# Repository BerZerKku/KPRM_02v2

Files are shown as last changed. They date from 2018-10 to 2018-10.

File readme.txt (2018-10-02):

Плата KPRM.
Сделана в OrCAD 16.6.

02v2

Код ПП: KPRM_02v2
Код ПП в сборе (1-16 команды): 2.141.180

Предназначена для использования в АВАНТ К400.

Изменения:
1. Обновлены элементы из базы (описания, сборка).
2. В преобразователе питания конденсатор С3 подключен на землю, а не в ОС. 
3. Элементы ОС преобразователя питания посажены на полигоны через термобарьеры.
4. Увеличин полигон для отвода тепла под DA1.
5. Отверстия крепления и разъема Х1 передвинуты согласно евромеханики. 
6. Поз. обозначения разъемов WAGO уменьшились на 1.
7. Добавлен разъем PLS-2 на землю.

Стэк:
18мкм  TOP
1.50мм e=4.5
18мкм  BOTTOM

Материал: FR4 
Финишное покрытие контактных площадок: HAL
Паяльная маска: зеленая.
Вырезы на плате нет.
Отверстия указаны ДО металлизации.
	Отв.	Метал.	Диам.	Кол.
	0.500	есть	0.4		220
	1.000	есть	1.0		194
	2.000	есть	1.8		64
	2.700	есть	2.7		2
	2.700	нет		2.7		2

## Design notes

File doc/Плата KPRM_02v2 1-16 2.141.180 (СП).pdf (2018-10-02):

Напечатано: 02 октября 2018 г. 12:02:07, Щеблыкин Михаил Владимирович
Поз. | Наименование | Корпус | Кол. | Поз. по Э3 | Примечание
| Документация
| Сборочный чертеж 2.141.180 | | 1
| Детали
1 | [KPRM_02v2] Печатная плата KPRM_02v2 2L/200um/0.4mm | | 1
| Прочее
| Реле
2 | [G3VM-351E] Реле G3VM-351E Omron | SOIC6 | 1 | AV1
3 | [G6S224DC] Реле G6S224DC 24VDC 2 Form C 0.5A/125VAC Omron | DIP8 | 16 | K1-K16
| Конденсаторы
7 | [1210-X7R-50V-10uF -10%] Чип-конденсатор 1210 X7R 50V 10uF 10% | 1210 | 2 | C1, C7 | Допустимые замены: [1210-X7R-50V-4.7uF-10%] Чип-конденсато р 1210 X7R 50V 4.7uF 10%
8 | [0805-X7R-50V-0.1u F-10%] [+]Чип-конденсатор 0805 X7R 50V 0.1uF 10% | 0805 | 4 | C2, C4, C5, C8
9 | [1206-X7R-50V-1uF-10%] [+] Чип-конденсатор 1206 X7R 50V 1uF 10% | 1206 | 1 | C3
10 | [0805-X7R-50V-0.01 uF-10%] Чип-конденсатор 0805 X7R 50V 0.01uF 10% | 0805 | 1 | C6

2.141.180

| Лист | № докум | Подп. | Дата
Разраб. | Щеблыкин М.В. | | 01.10.2018 | Плата KPRM_02v2 1-16 (Плата KPRM_02v2 1-16) | Лит. | Лист | Листов
Провер. | Вершинин А.С. | | 01.10.2018 | | | 1 | 4
Т.контр. | Бокова Т.И. | | 01.10.2018 | | Прософт-Системы
Н.контр. | Назаренко А.Н. | | 01.10.2018
Утв. | Чирков А.Г. | | 01.10.2018

| Предохранители,держатели предохранителей
18 | [P6SMB300CA] Диод P6SMB300CA | SMB(DO -214 | 32 | VD1, VD2, VD4-VD33
| Резисторы
20 | [1206-18K-5%] Чип-резистор 1206 18K 5% | 1206 | 16 | R1, R24-R38
21 | [1206-2K-5%] Чип-резистор 1206 2K 5% | 1206 | 18 | R2-R18, R22
22 | [1206-270-5%] Чип-резистор 1206 270 5% | 1206 | 1 | R19
23 | [1206-1K-5%] Чип-резистор 1206 1K 5% | 1206 | 1 | R20
24 | [1206-20K-5%] Чип-резистор 1206 20K 5% | 1206 | 1 | R21
25 | [1206-10K-5%] Чип-резистор 1206 10K 5% | 1206 | 1 | R23
26 | [1206x4-4.7K-5%] Чип-резисторная сборка 1206x4 4.7K 5% | SMD8 | 4 | RR1-RR4
| Микросхемы
32 | [LM317EMP] Микросхема LM317EMP SOT-223 TI | SOT223 | 1 | DA1 | Допустимые замены: [LM317AEMP] Микросхема LM317AEMP SOT223 TI
33 | [LM293D] Микросхема LM293D сдвоенный компаратор SO8 STM | SOIC8 | 1 | DA2
34 | [ULN2803ADW] Микросхема ULN2803ADW SOIC18 TI | SOIC18 | 4 | DD1-DD4

2.141.180

Лист

2 Изм | Лист | № докум | Подп. | Дата

| Диоды,светодиоды,супрессоры,стабилитроны
38 | [STPS160U] Диод STPS160U SMB STM | SMB(DO -214 | 1 | VD3
| Соединители
42 | [09031646921] Соединитель DIN EN 60303-2-C64MS-C1A-2 | DIN96 | 1 | X1
43 | [231-576/001-000] Вилка 1,2X1,2 шаг 5,08 мм (50 шт) | 16 | 2 | X2, X4
44 | [232-376] Угловая Вилка 5,08 мм 16-поз (25 шт) | 16 | 2 | X3, X5
45 | [PLS-40] Разъем PLS-40 | 2 | 2 | X6

2.141.180

Лист

3 Изм | Лист | № докум | Подп. | Дата

Лист регистрации ревизий

№ ревизии | № замененных (измененных) страниц | Дата ревизии | Краткое содержание и причина внесения изменений | Примечание
0 | вновь | 01.10.18

2.141.180

4

Лист Изм. | Лист | № докум. | Подп. | Дата

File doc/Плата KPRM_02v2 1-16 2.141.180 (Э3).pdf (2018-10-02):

K

8C | 11 7C | 12 6C | 13 5C | 14 4C | 15 3C | 16 2C | 17 1C | 18

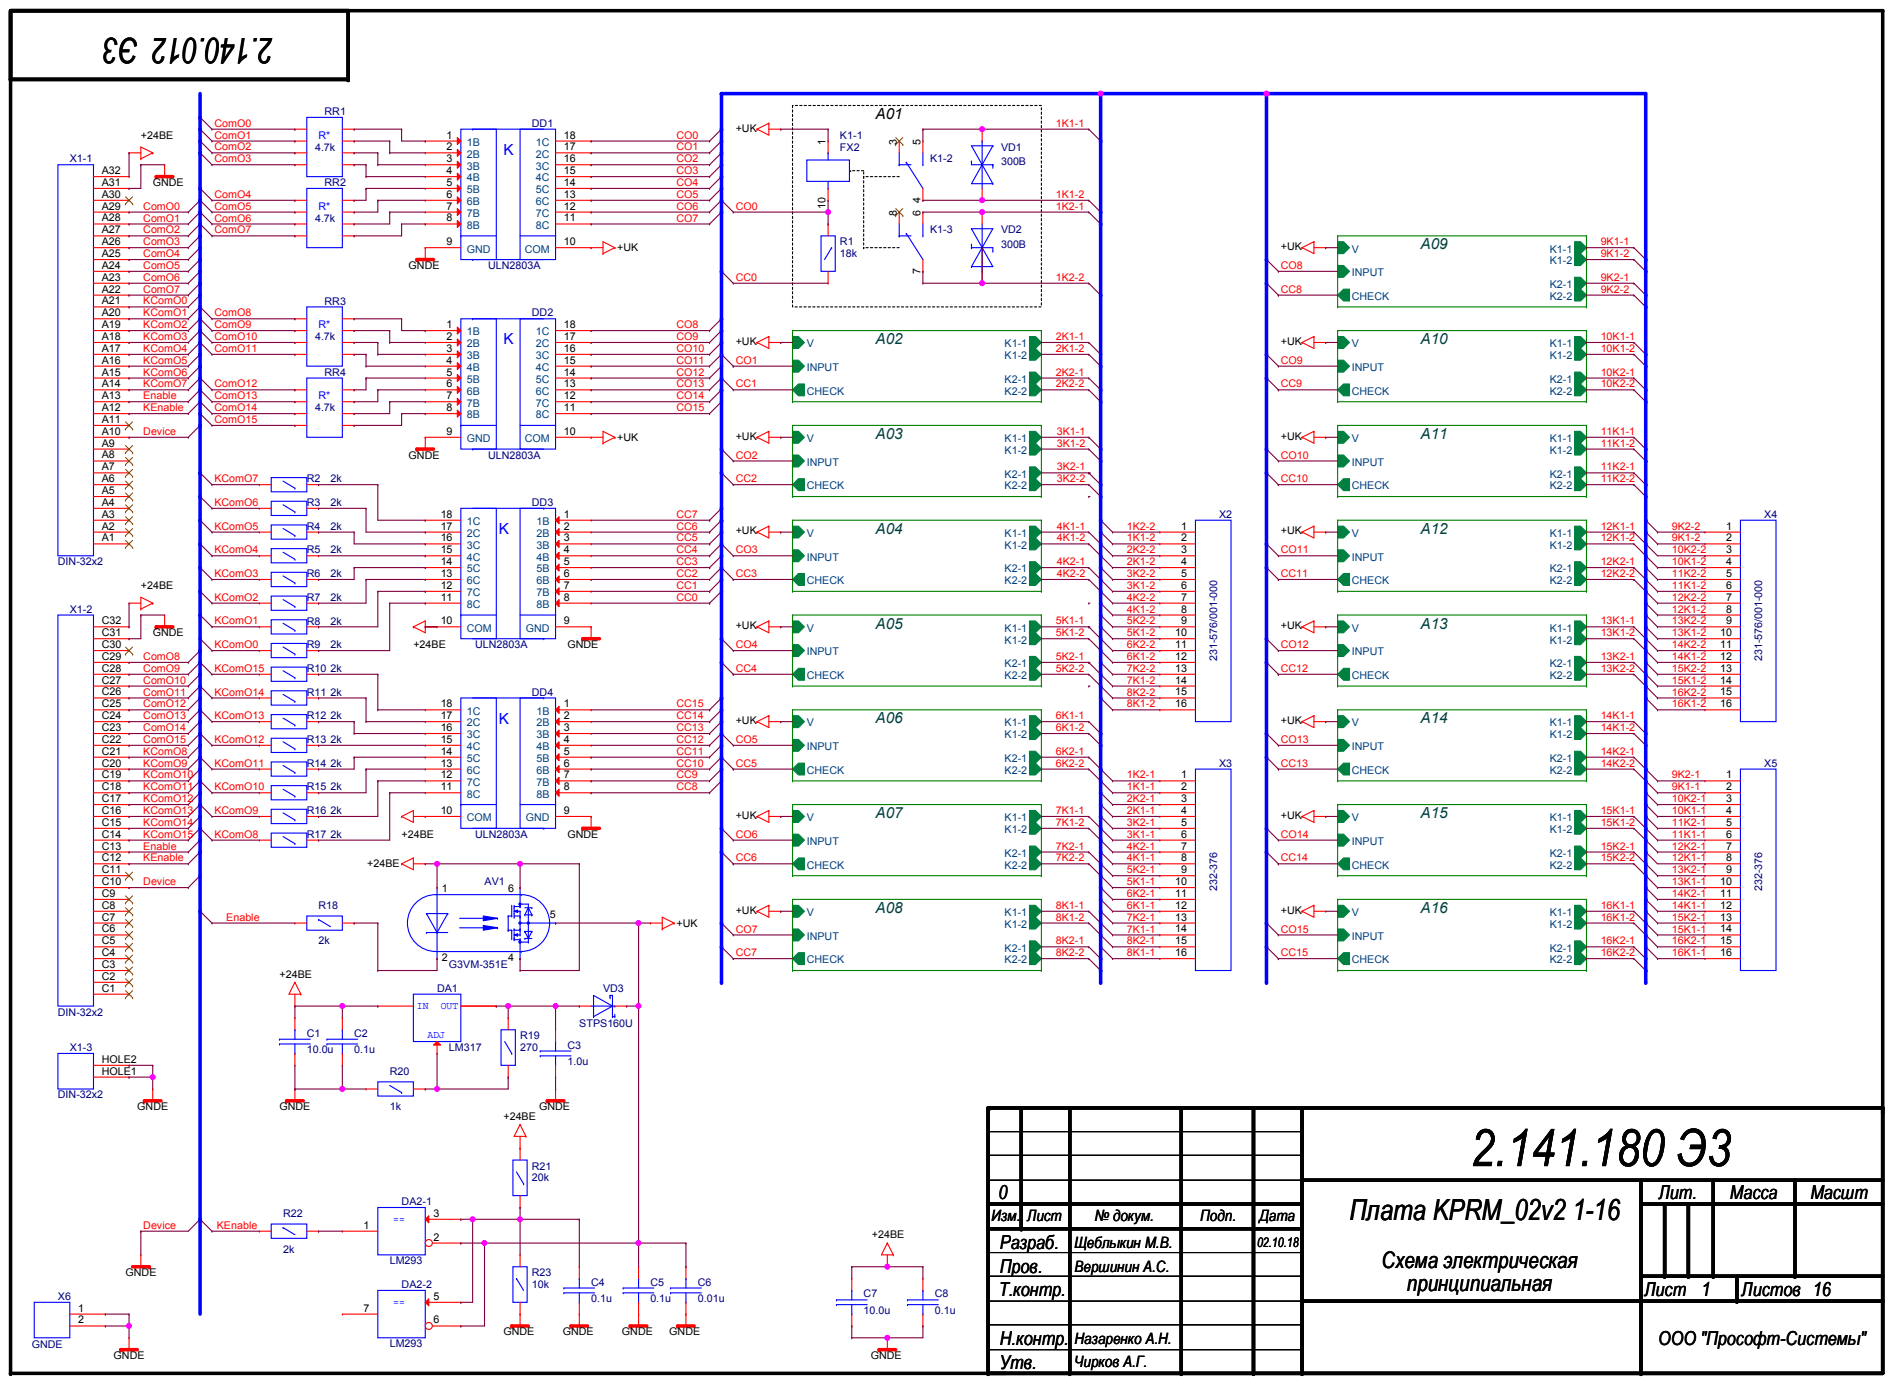
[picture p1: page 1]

0 | | | | | Плата KPRM_02v2 1-16 Плата KPRM_02v2 1-16 Плата KPRM_02v2 1-16 Схема электрическая Схема электрическая Схема электрическая | Лит. | Масса Масса Масса | Масшт Масшт Масшт
Изм. Изм. Изм. | Лист Лист Лист | № докум. № докум. № докум. | Подп. Подп. Подп. | Дата Дата Дата
Разраб. Разраб. Разраб. | | Щеблыкин М.В. Щеблыкин М.В. Щеблыкин М.В. | | 02.10.18 02.10.18 02.10.18
Пров. Пров. Пров. | | Вершинин А.С. Вершинин А.С. Вершинин А.С.
принципиальная Т.контр. принципиальная Т.контр. принципиальная Т.контр. | Лист Лист Лист 1 16 1 16 1 16 | Листов Листов Листов

Н.контр. Н.контр. Н.контр. | Назаренко А.Н. Назаренко А.Н. Назаренко А.Н.
Утв. Утв. Утв. | Чирков А.Г. Чирков А.Г. Чирков А.Г.

ООО "Прософт-Системы" ООО "Прософт-Системы" ООО "Прософт-Системы"

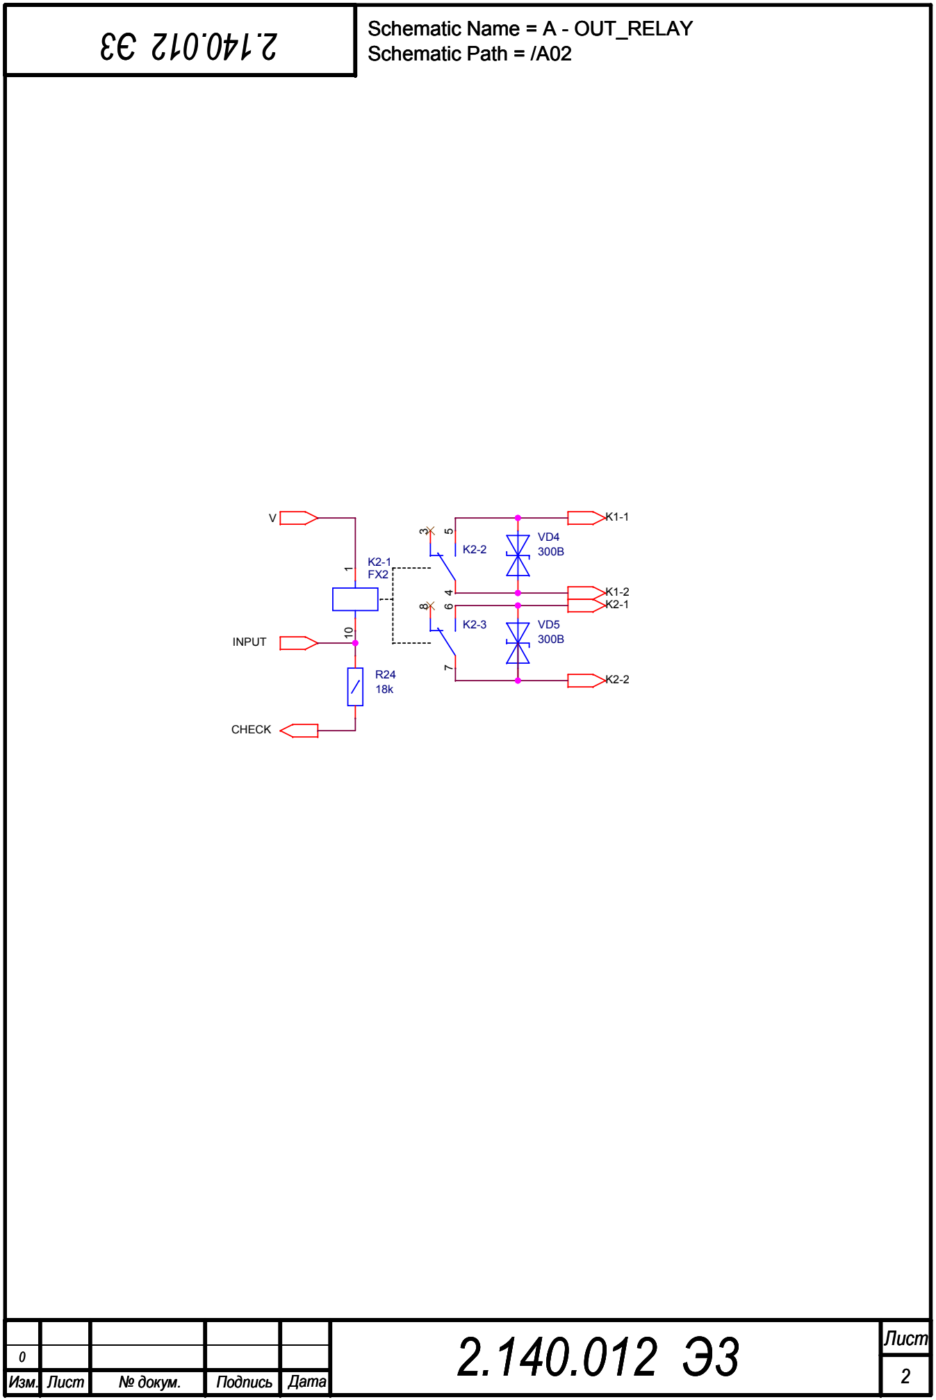
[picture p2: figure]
CHECK; INPUT; Изм.; Лист; № докум.; Подпись; Дата; Schematic Name = A - OUT_RELAY Schematic Path = /A02; Schematic Path = /A02 2.140.012 Э3

# Лист 2.140.012 Э3 Лист 2.140.012 Э3 Лист 2.140.012 Э3 2 ⁰ 2 ⁰ 2 ⁰

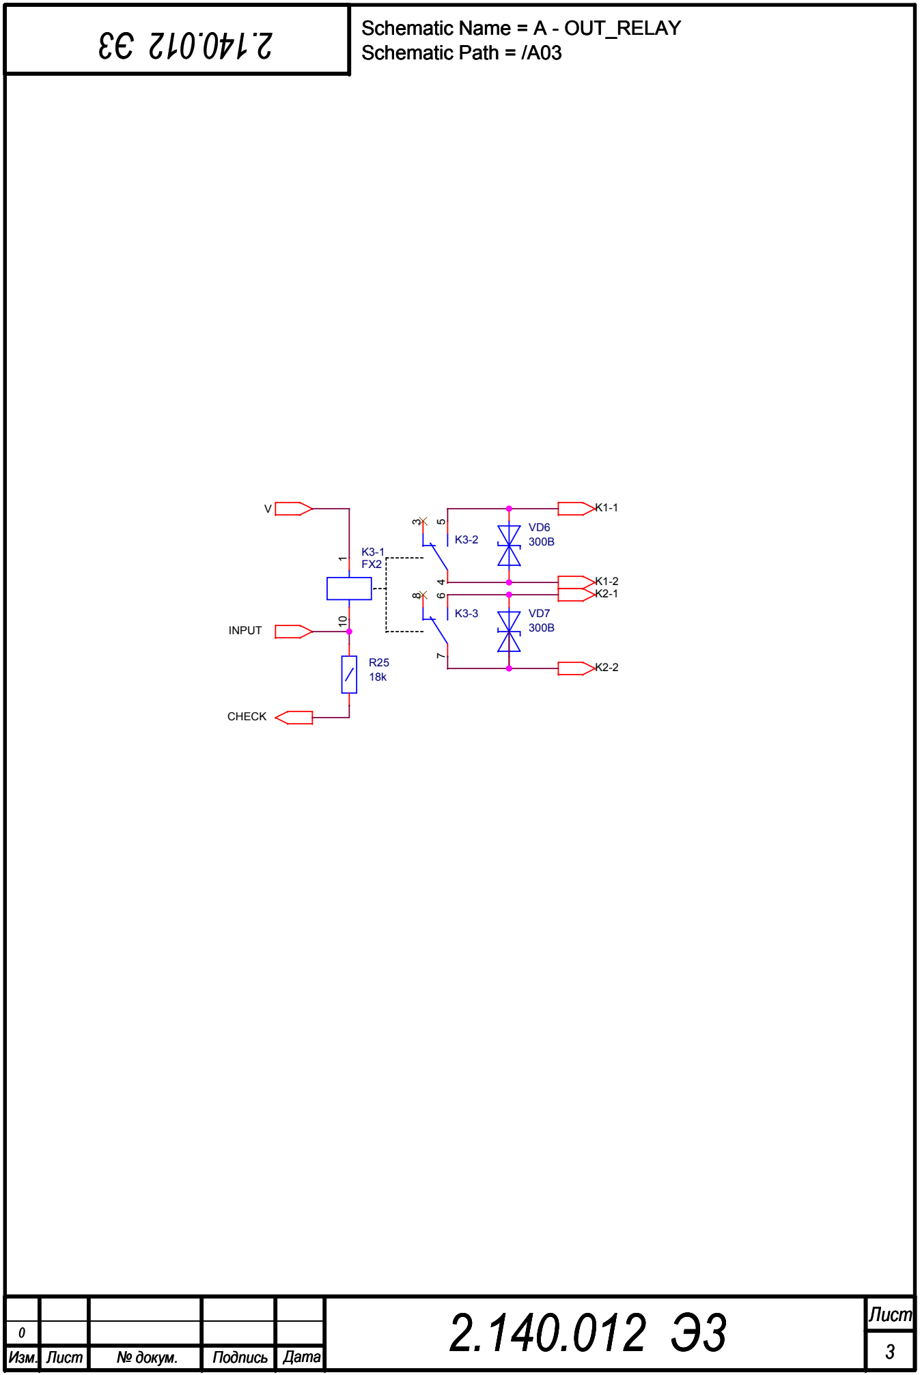
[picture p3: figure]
CHECK; INPUT; Лист 2.140.012 Э3; Schematic Path = /A03 2.140.012 Э3

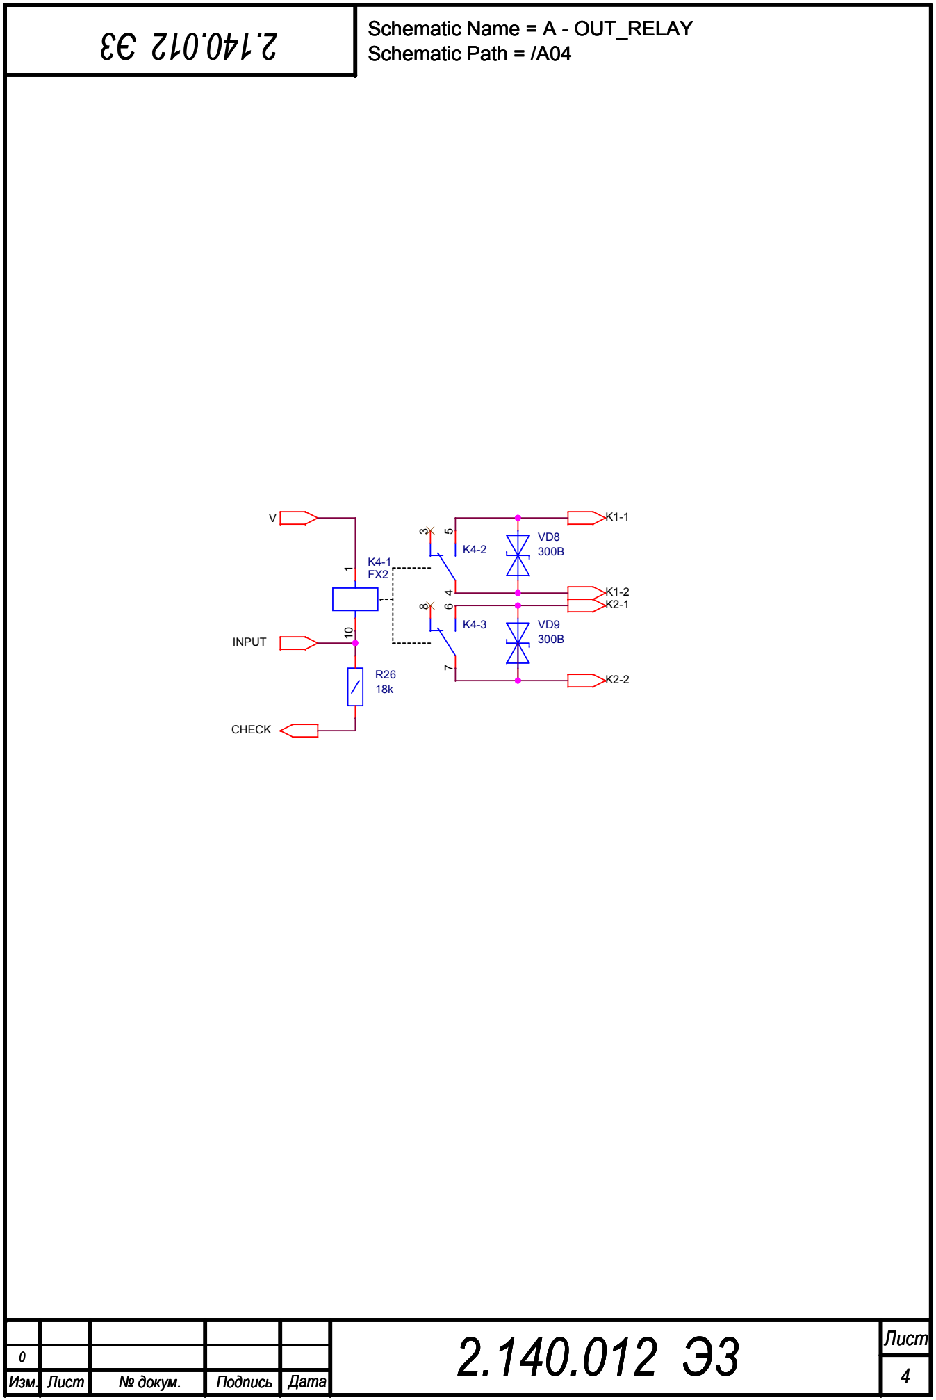
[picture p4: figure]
CHECK; INPUT; Лист 2.140.012 Э3; Schematic Path = /A04 2.140.012 Э3

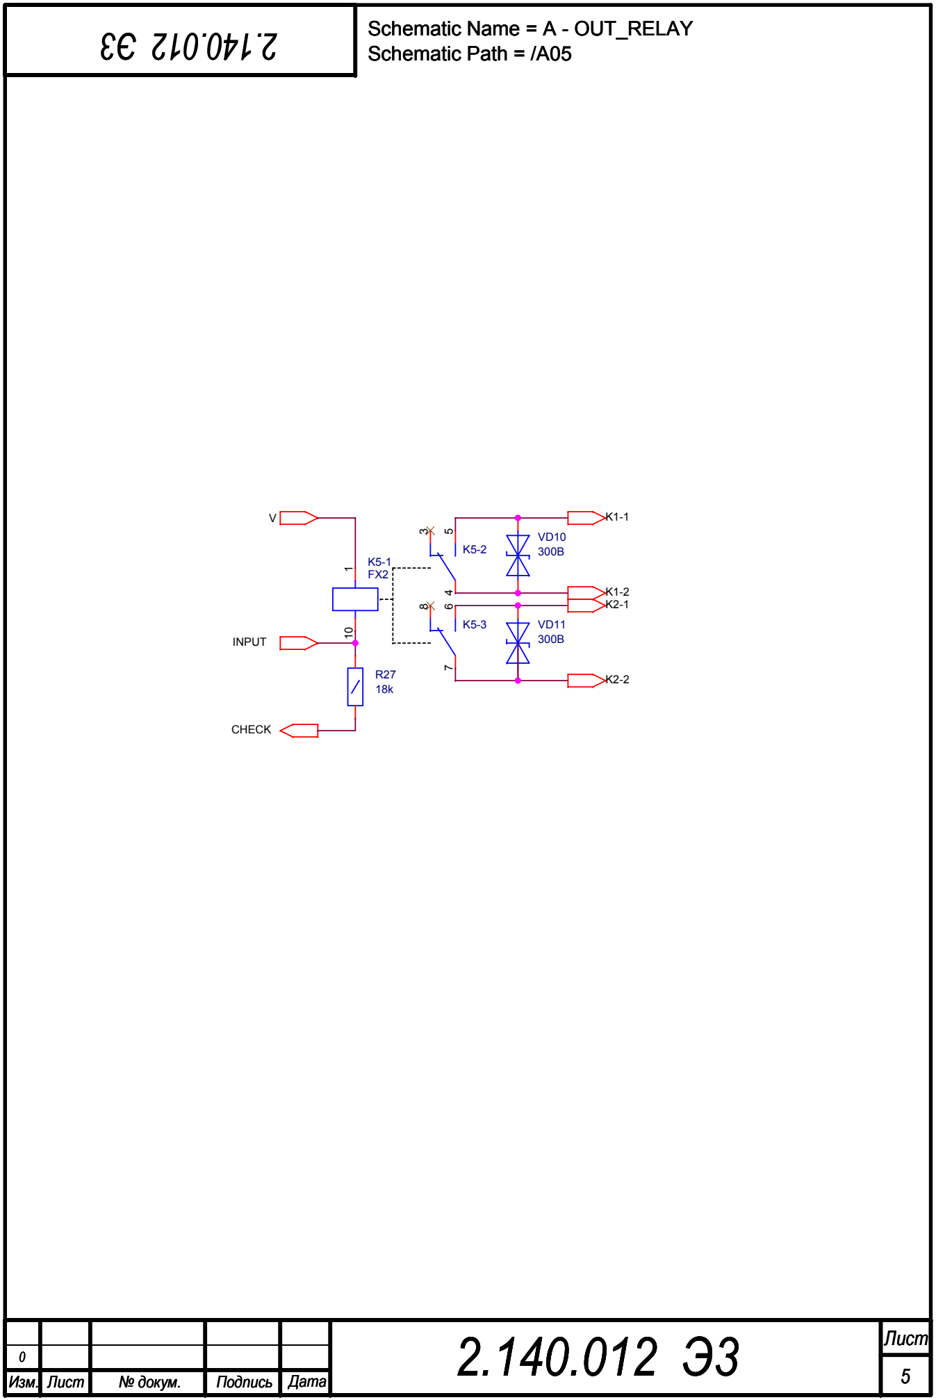
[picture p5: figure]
CHECK; INPUT; Лист 2.140.012 Э3; Schematic Path = /A05 2.140.012 Э3

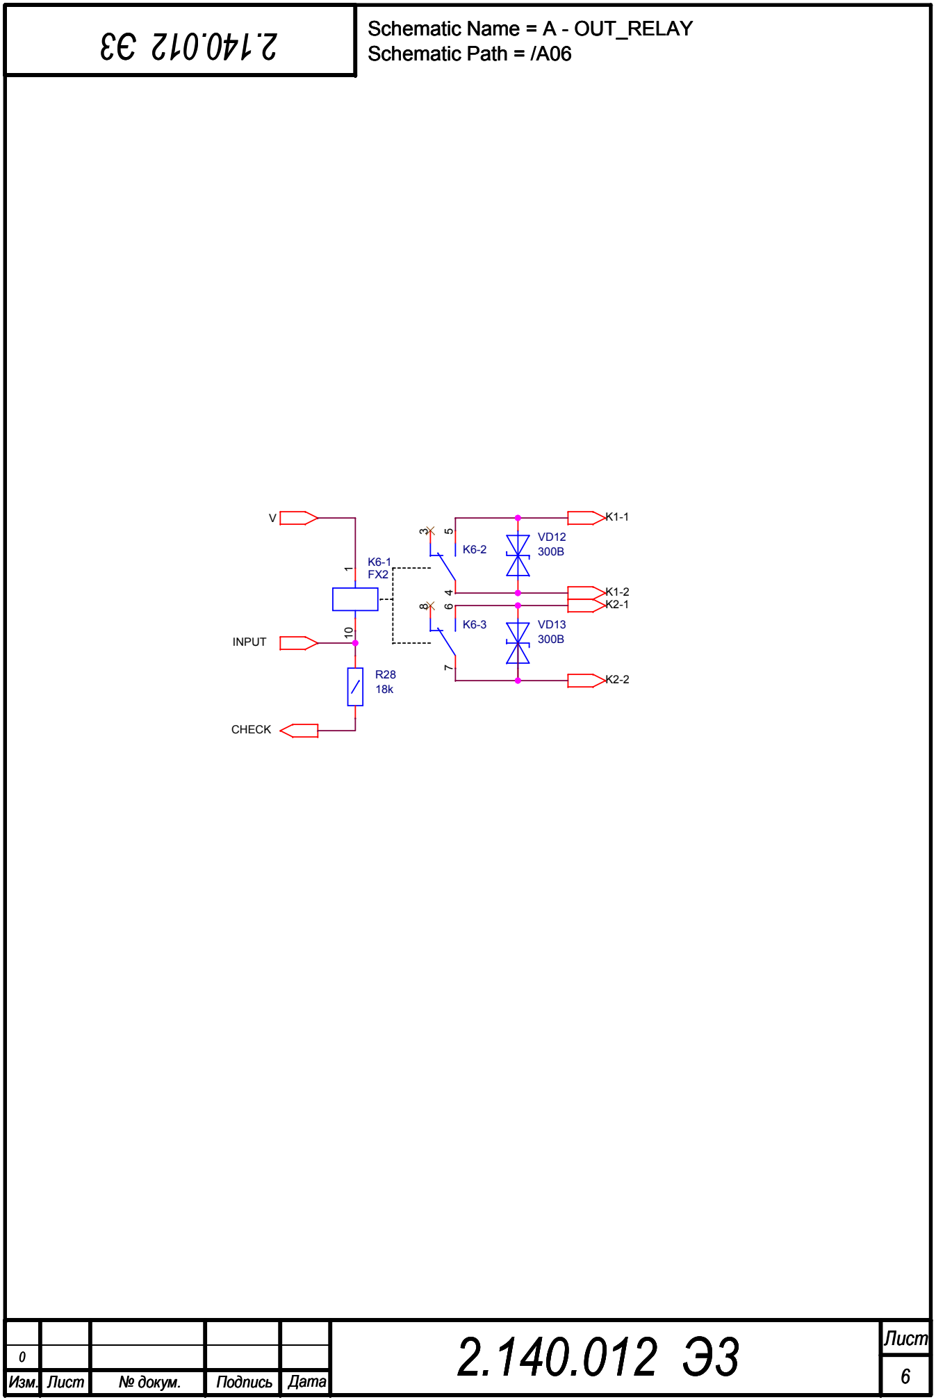
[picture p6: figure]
CHECK; INPUT; Лист 2.140.012 Э3; Schematic Path = /A06 2.140.012 Э3

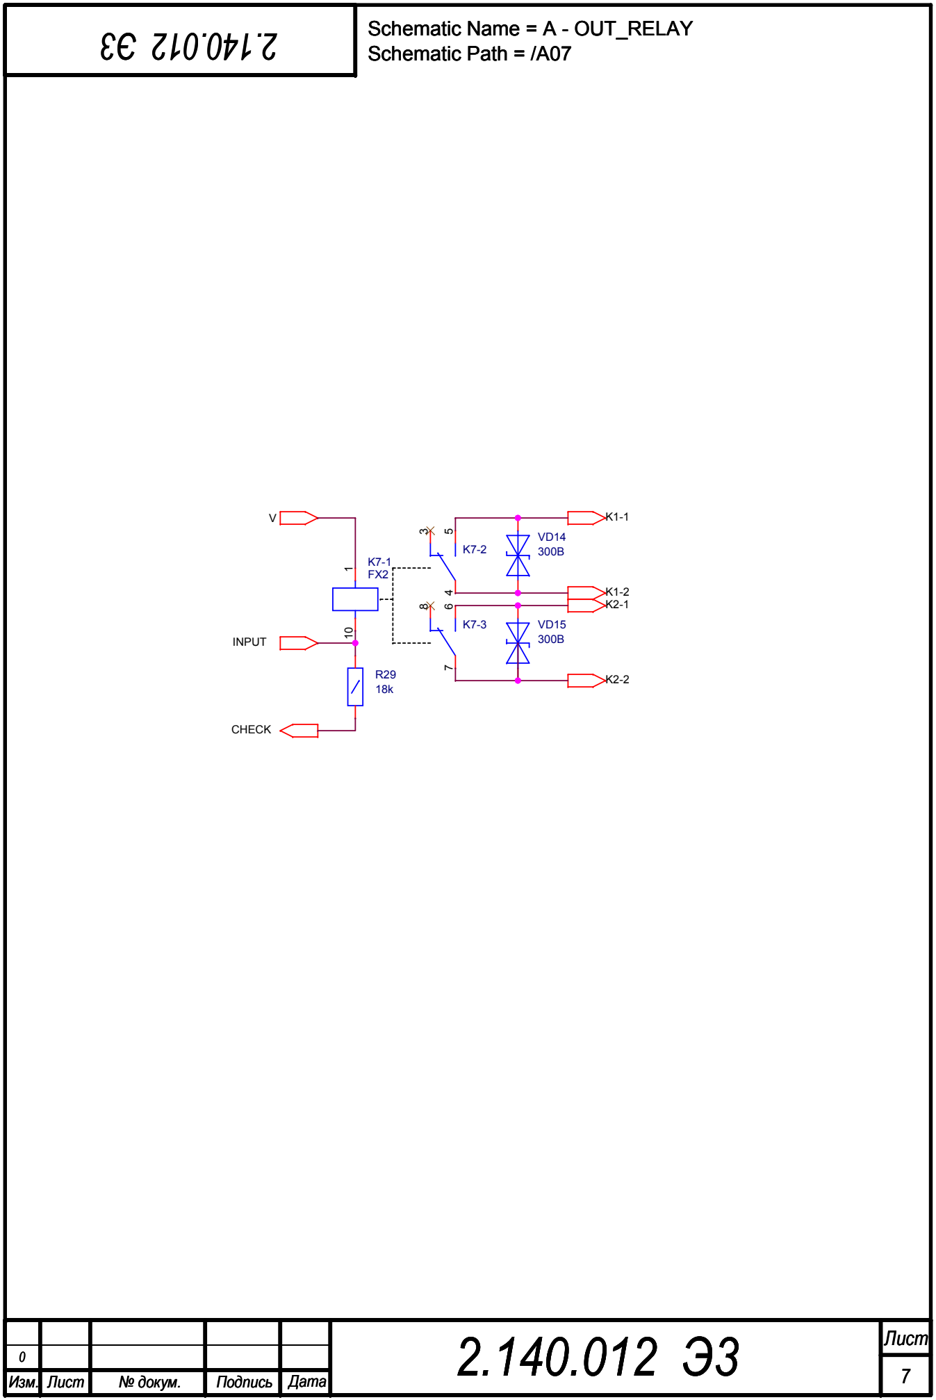
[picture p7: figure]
CHECK; INPUT; Лист 2.140.012 Э3; Schematic Path = /A07 2.140.012 Э3

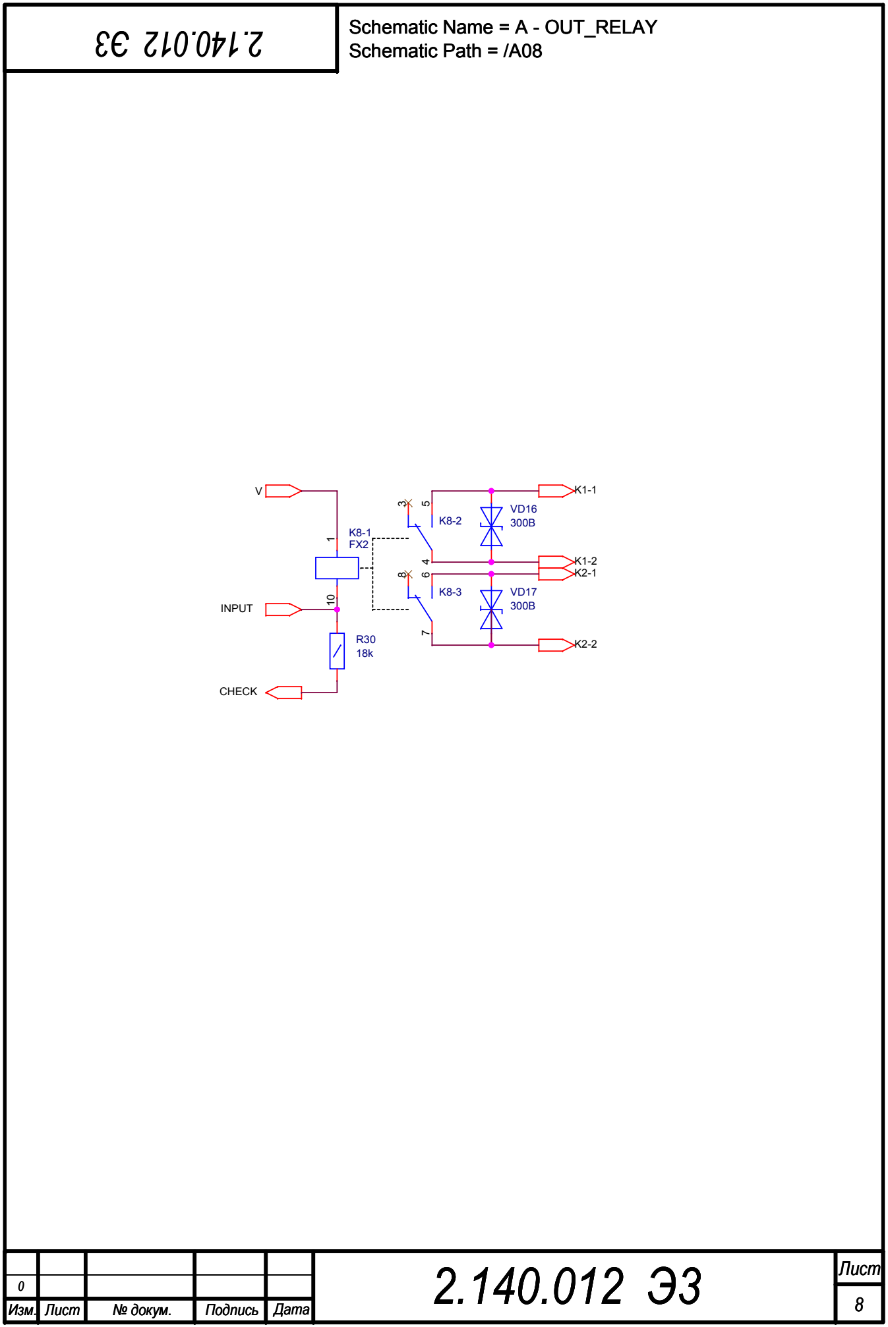
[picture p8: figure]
CHECK; INPUT; Лист 2.140.012 Э3; Schematic Path = /A08 2.140.012 Э3

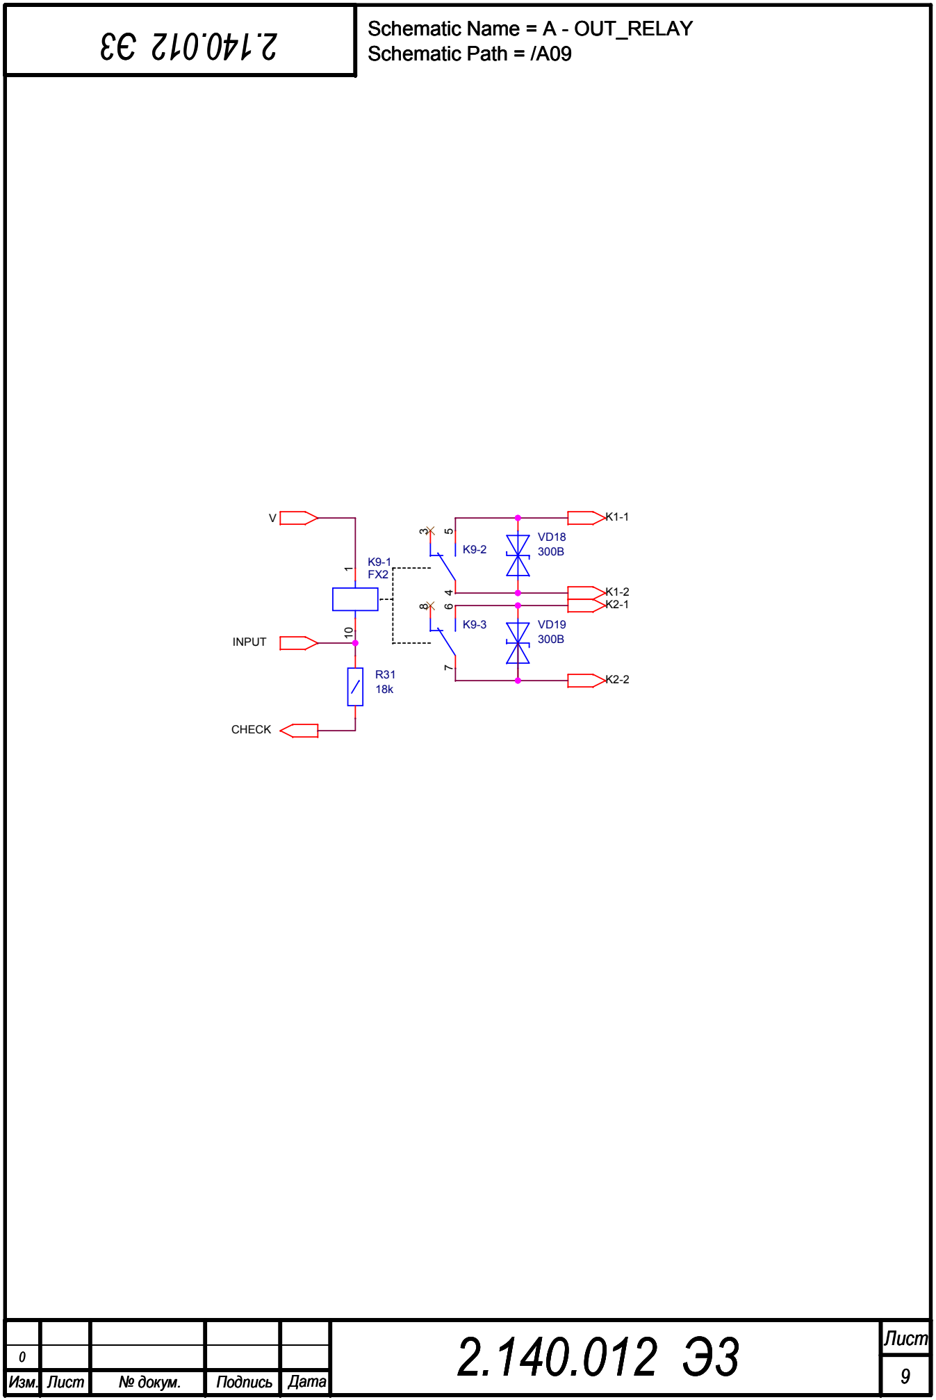
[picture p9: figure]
CHECK; INPUT; Лист 2.140.012 Э3; Schematic Path = /A09 2.140.012 Э3

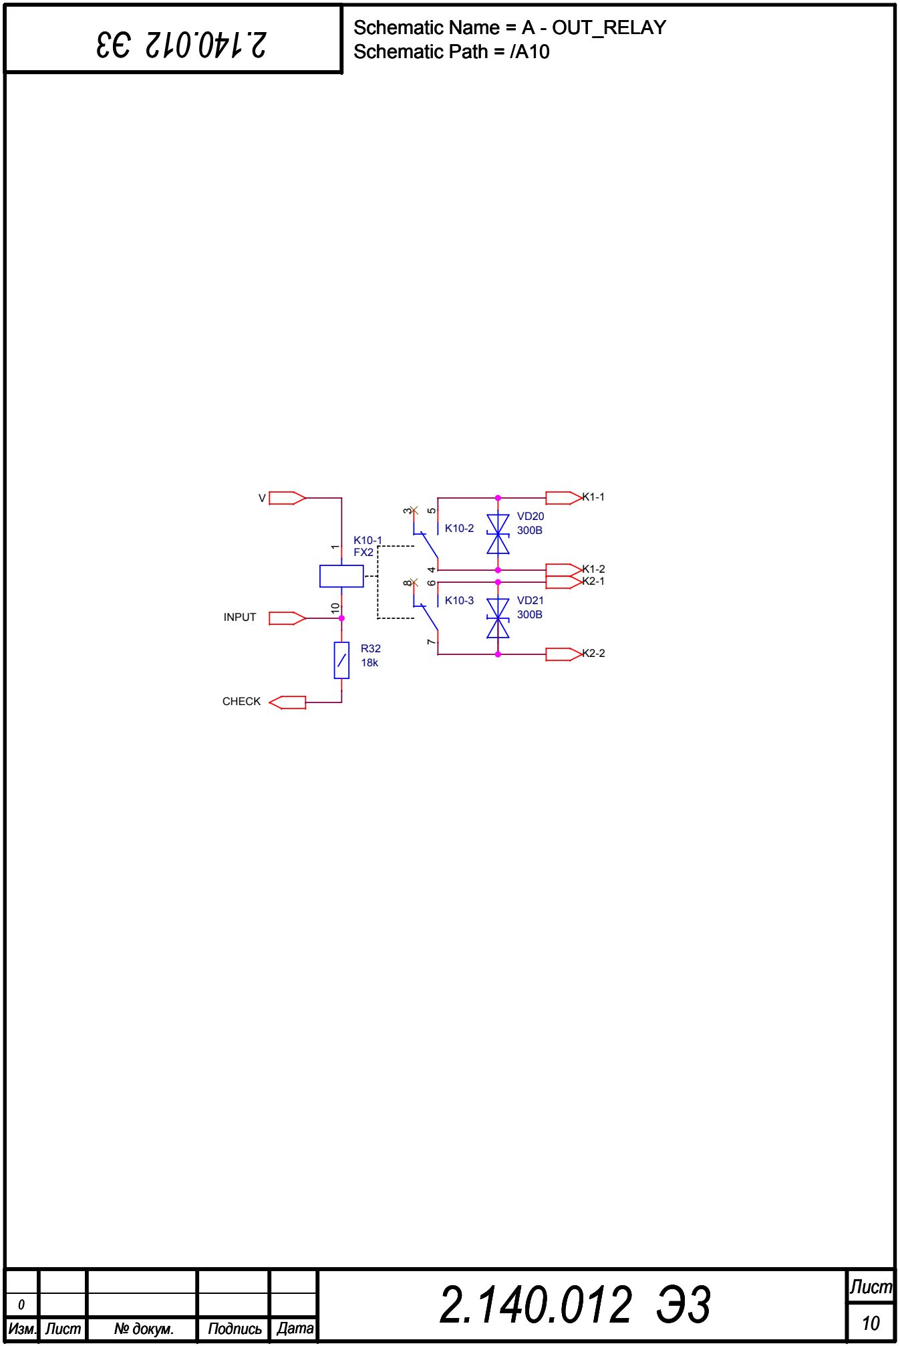
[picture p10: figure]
CHECK; INPUT; Лист 2.140.012 Э3; Schematic Path = /A10 2.140.012 Э3

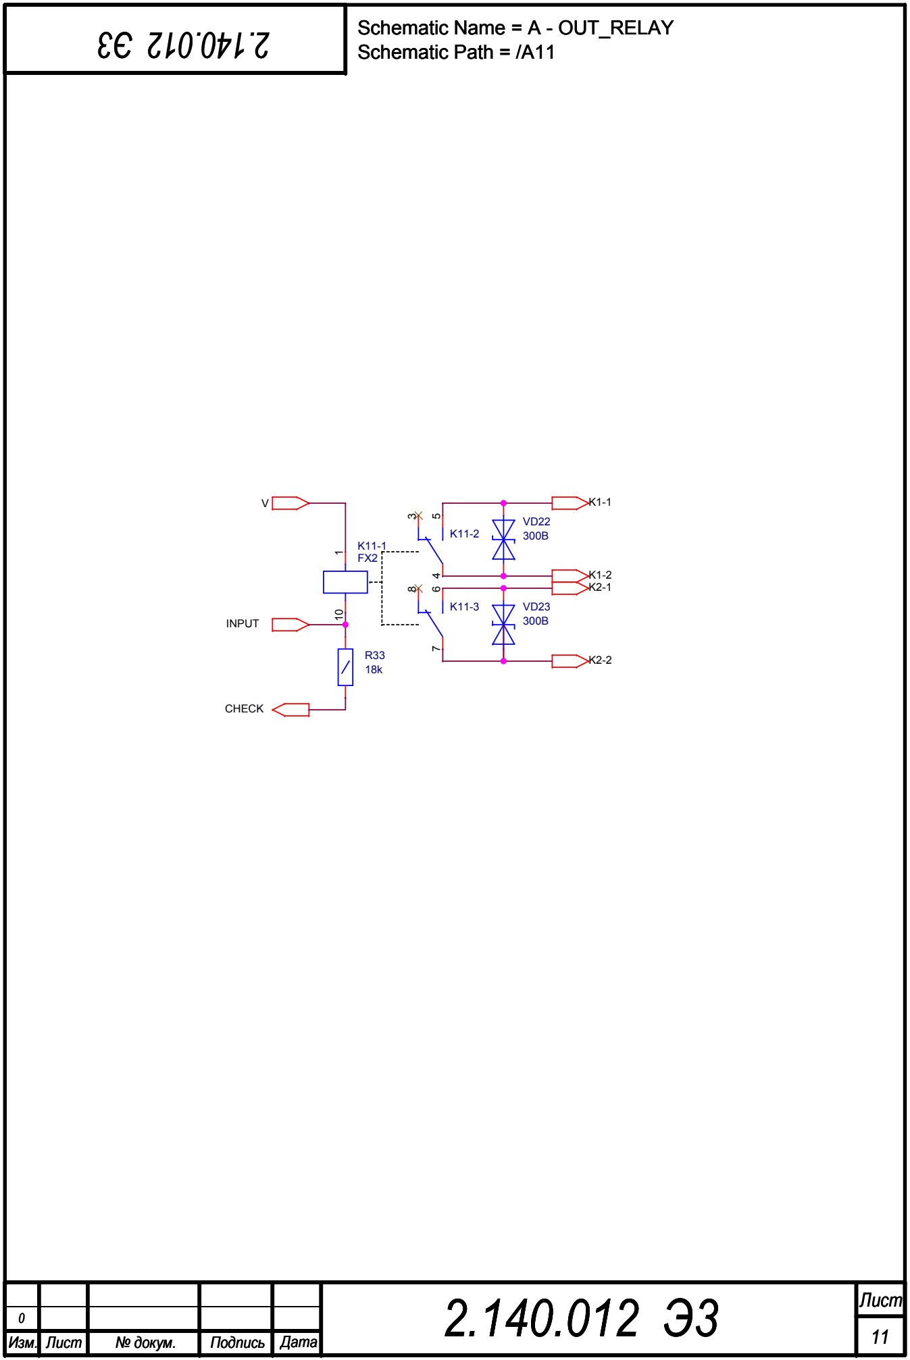
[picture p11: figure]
CHECK; INPUT; Лист 2.140.012 Э3; Schematic Path = /A11 2.140.012 Э3

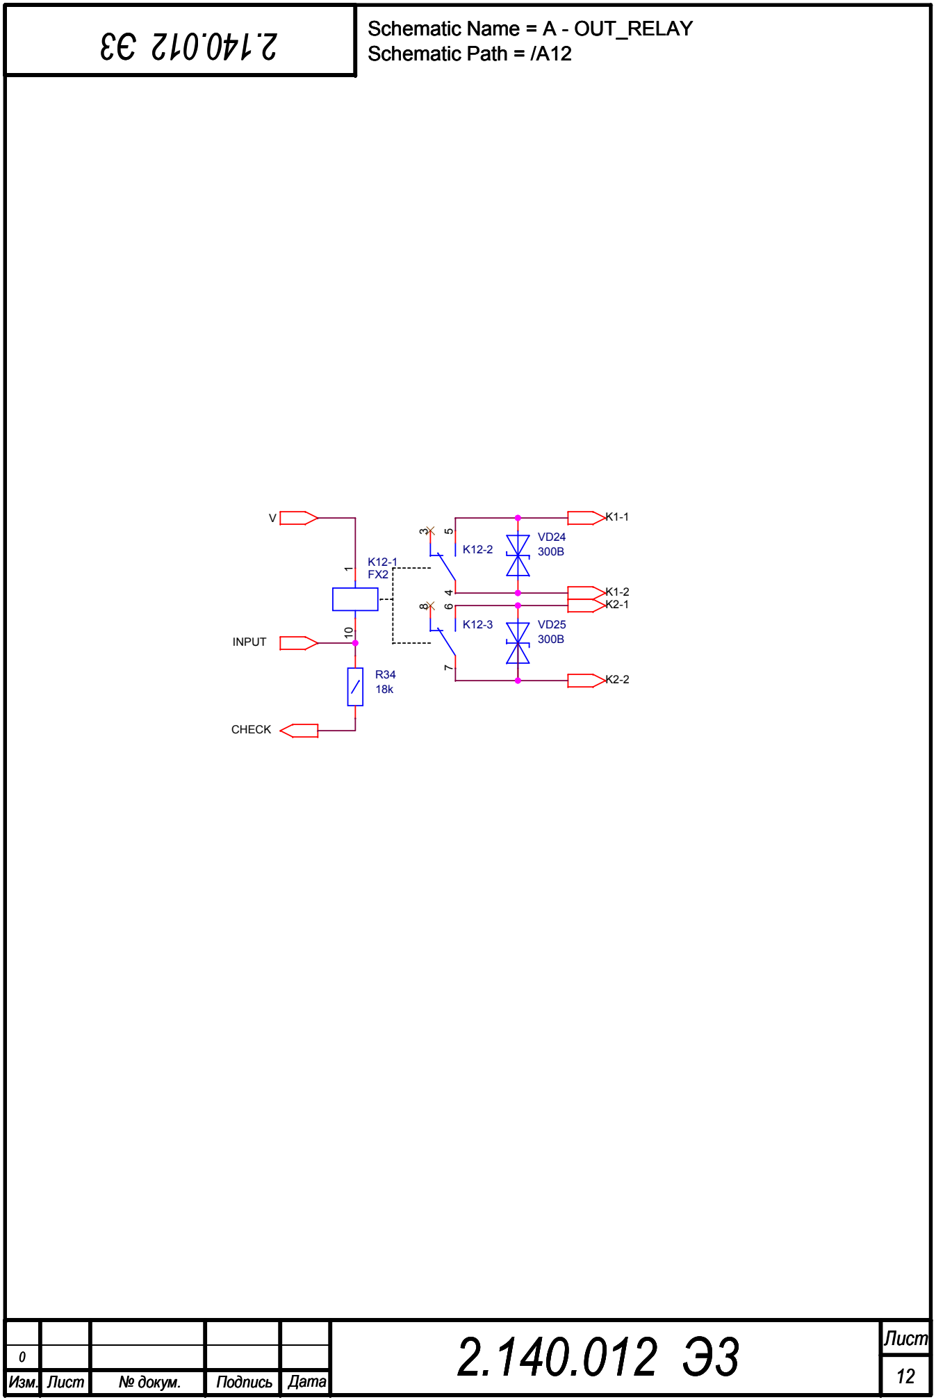
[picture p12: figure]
CHECK; INPUT; Лист 2.140.012 Э3; Schematic Path = /A12 2.140.012 Э3

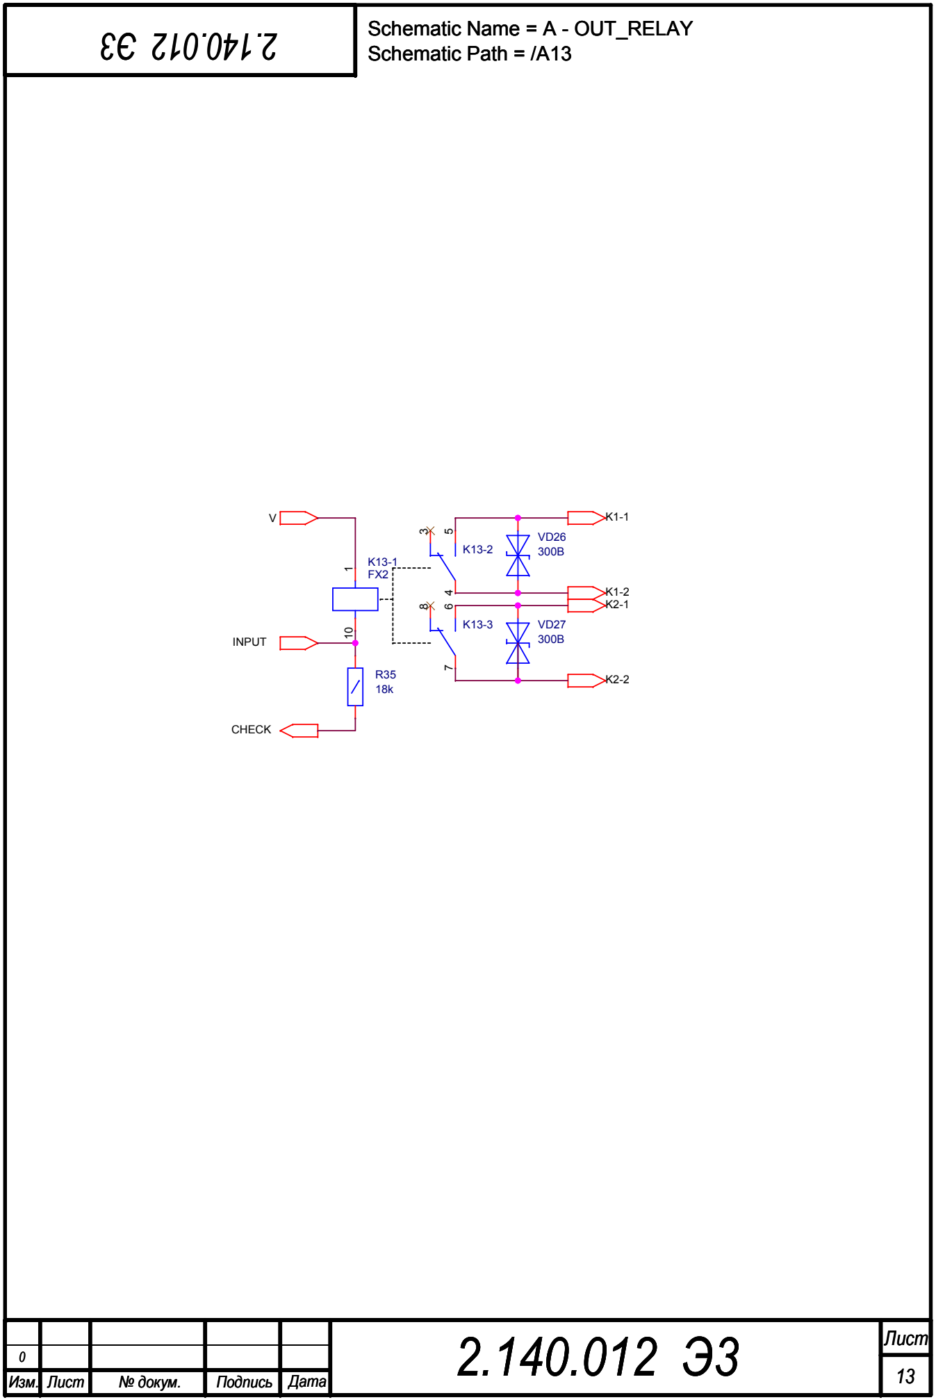
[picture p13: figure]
CHECK; INPUT; Лист 2.140.012 Э3; Schematic Path = /A13 2.140.012 Э3

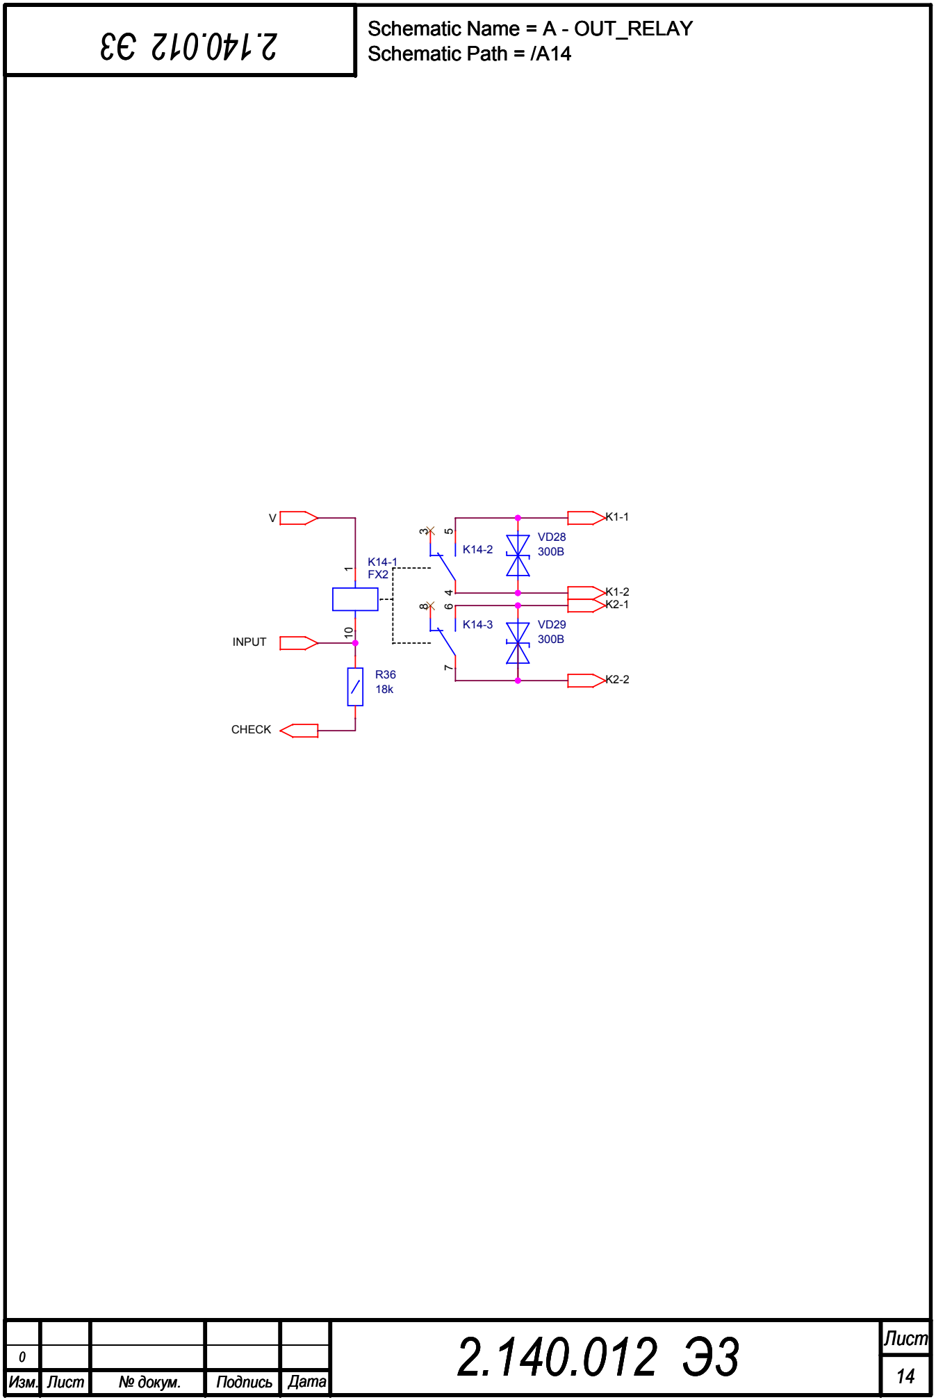
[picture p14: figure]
CHECK; INPUT; Лист 2.140.012 Э3; Schematic Path = /A14 2.140.012 Э3

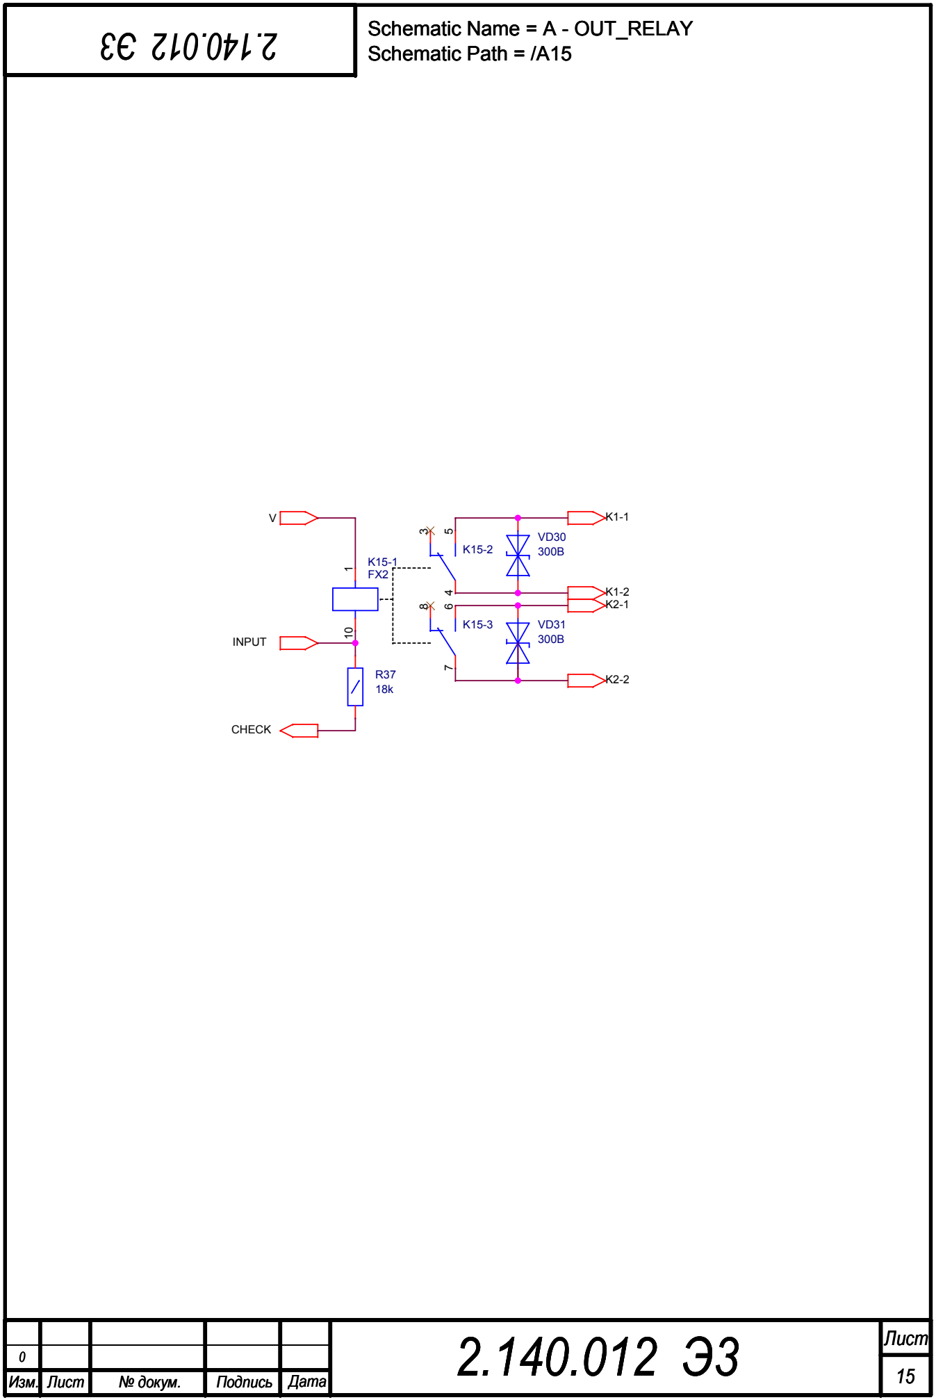
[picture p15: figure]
CHECK; INPUT; Лист 2.140.012 Э3; Schematic Path = /A15 2.140.012 Э3

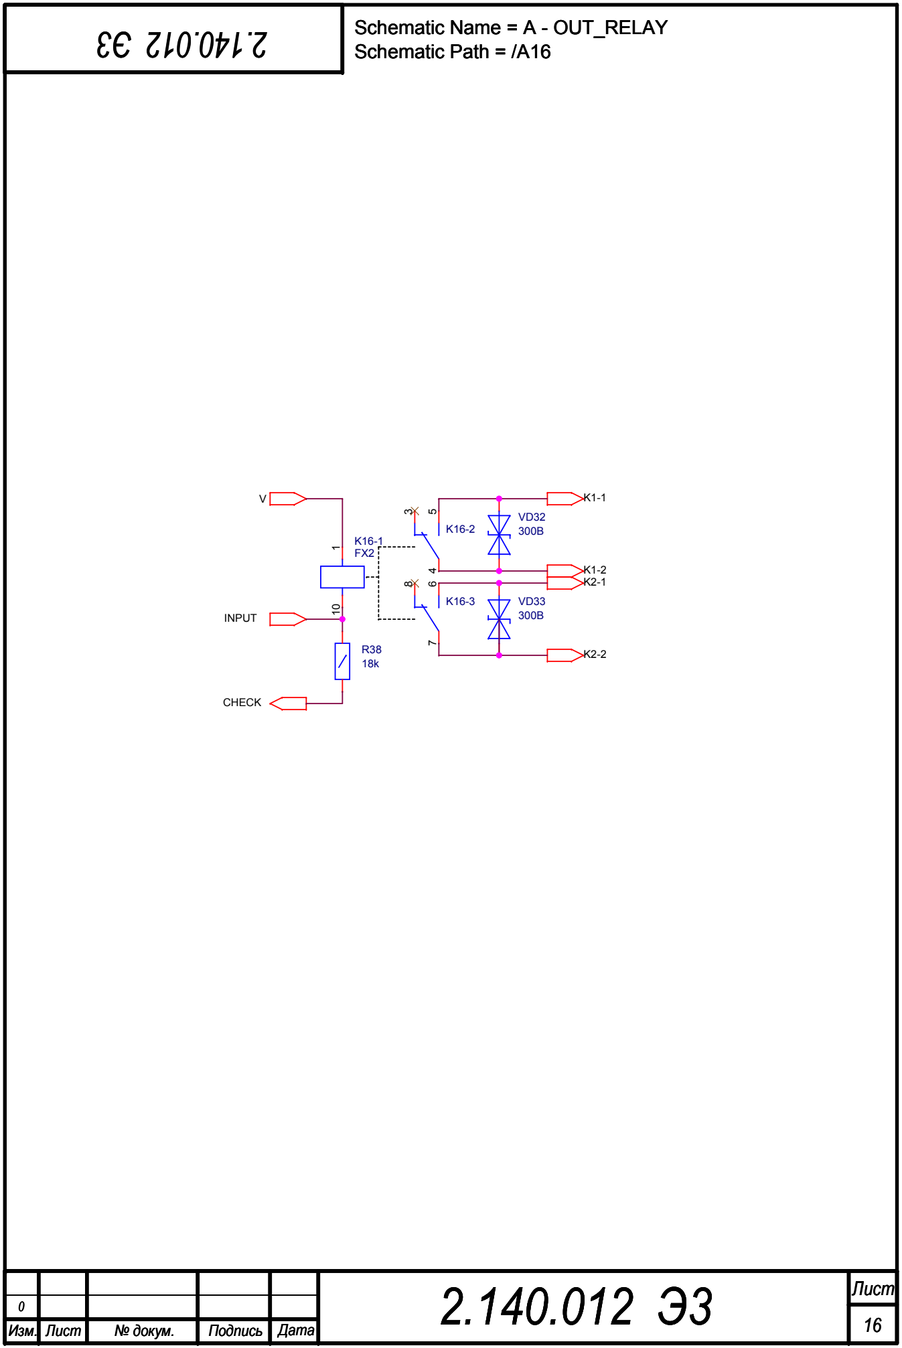
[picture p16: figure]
CHECK; INPUT; Лист 2.140.012 Э3; Schematic Path = /A16 2.140.012 Э3

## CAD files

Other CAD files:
pcb/symbols/diom5236x261n_np.psm

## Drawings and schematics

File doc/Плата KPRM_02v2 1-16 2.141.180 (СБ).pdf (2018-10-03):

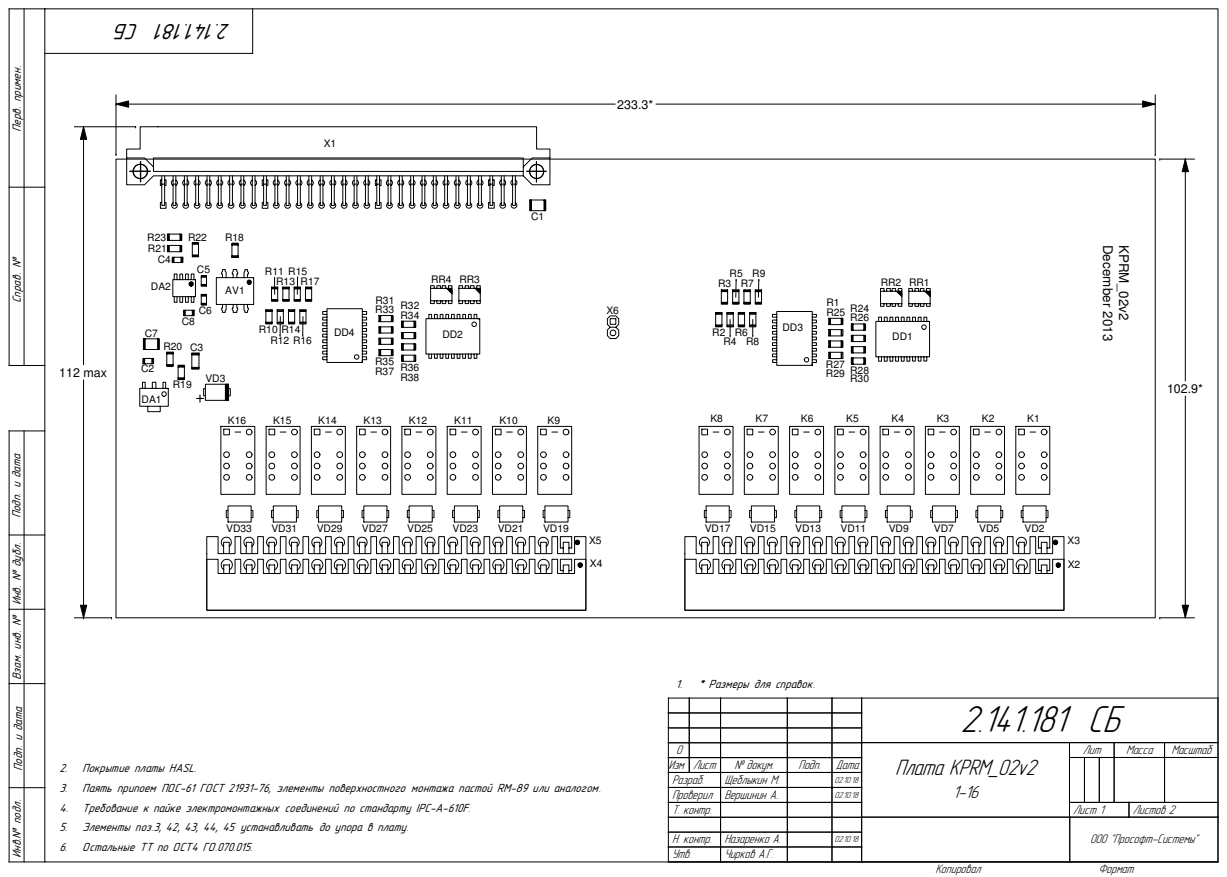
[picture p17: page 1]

Инв.№ подл. Подп. и дата Взам. инв. № Инв. № дубл. Подп. и дата Справ. № Перв. примен. C4 X5 RR4 RR3 RR2 RR1 K16 K15 K14 K13 K12 K11 K10 K9 K8 K7 K6 K5 K4 K3 K2 K1 DD4 DD3 DD2 DD1 DA2 X6 VD33 VD31 VD29 VD2 DA1 VD27 VD25 VD15 VD13 VD9 VD7 VD5 VD3 VD23 VD17 VD11 R4 R3 R16 R15 R14 R2 R13 R1 R28 R27 R26 R25 R9 R8 R5 R34 R33 R32 R29 R22 R21R20 R17 R10 R36 R35 R24 R23 R12 R11 R38 R37 C8 C5C6 C3 C1 C7 C2 AV1 X4 R7 R6 R31 R30 R19 R18 X1 X2X3 VD21 VD19 233.3* 112 max 102.9*

0 | | | | | Ïëàòà KPRM_02v2 1-16 | Ëèò | Ìàññà | Ìàñøòàá
Èçì | Ëèñò | ¹ äîêóì. | Ïîäï. | Äàòà
Ðàçðàá. | | Ùåáëûêèí Ì. | | 02.10.18
Ïðîâåðèë | | Âåðøèíèí À.. | | 02.10.18
Ò. êîíòð. | | | | | Ëèñò 1 | Ëèñòîâ 2

2. Покрытие платы HASL.
3. Паять припоем ПОС-61 ГОСТ 21931-76, элементы поверхностного монтажа пастой RM-89 или аналогом.
4. Требование к пайке электромонтажных соединений по стандарту IPC-A-610F.
5. Элементы поз.3, 42, 43, 44, 45 устанавливать до упора в плату.
6. Остальные ТТ по ОСТ4 ГО.070.015.

Í. êîíòð. | Íàçàðåíêî À. | 02.10.18
Óòâ. | ×èðêîâ À.Ã.

ÎÎÎ "Ïðîñîôò-Ñèñòåìû"

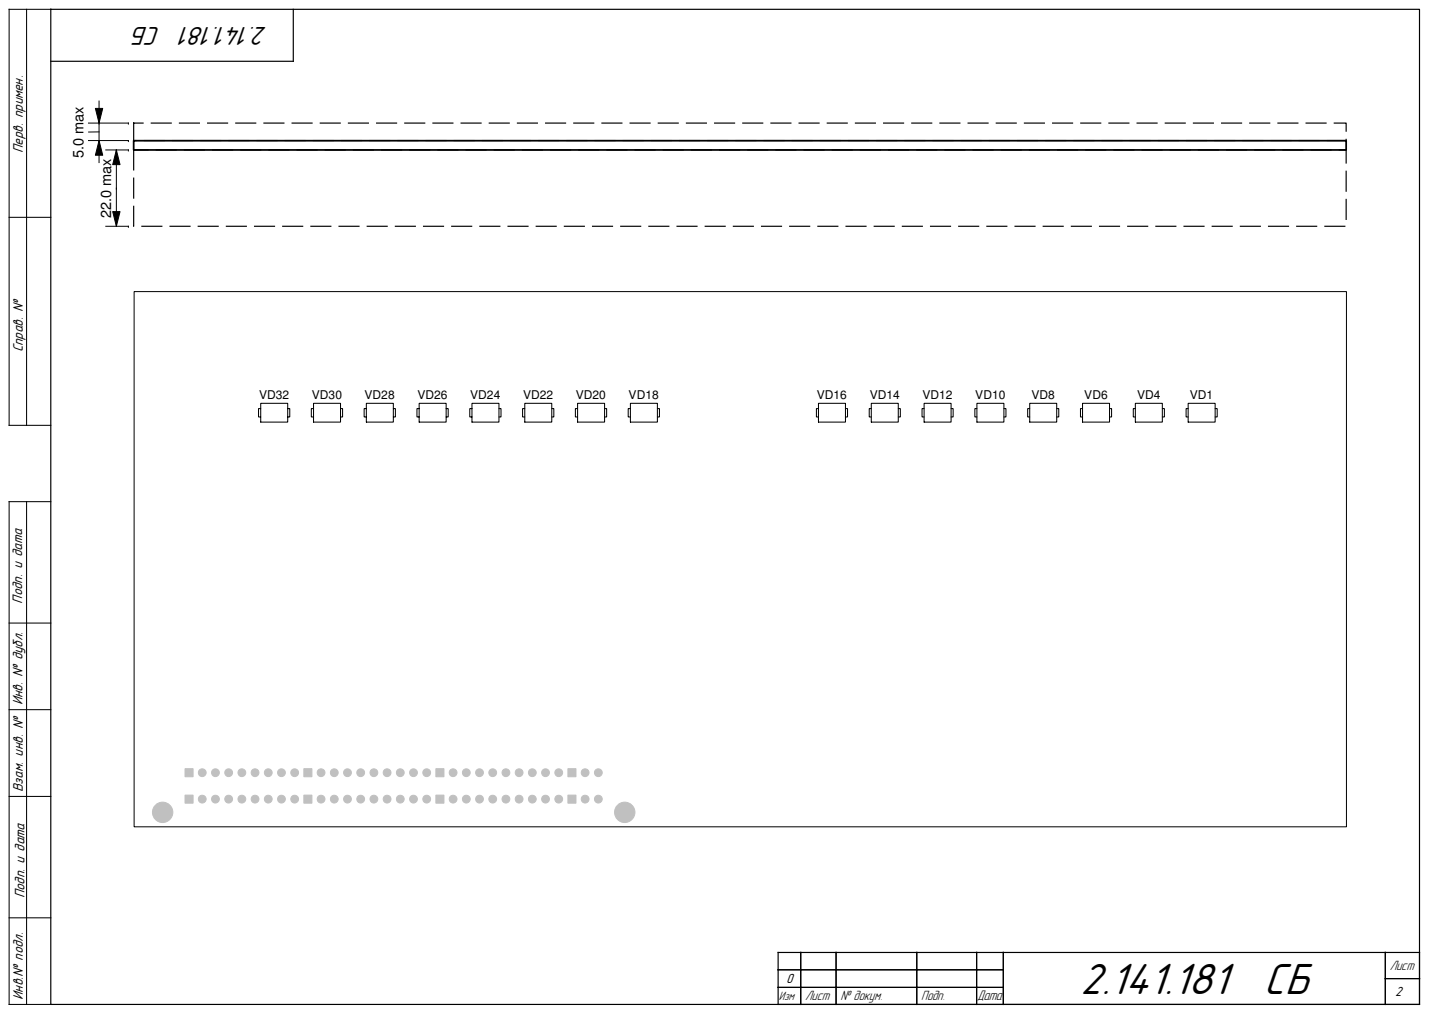
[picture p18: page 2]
Èçì; Ëèñò; ¹ äîêóì.; Ïîäï.; Äàòà; Ëèñò 2; 22.0 max; 5.0 max

Инв.№ подл. Подп. и дата Взам. инв. № Инв. № дубл. Подп. и дата Справ. № Перв. примен.

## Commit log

2013-12-20 Доработанная версия 02v1.
    [KPRM_02v2.DSN, KPRM_02v2.brd, nc_param.txt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]
2013-12-21 Мелкие коррекции касательно СП.
2014-02-07 В СП добавлены DIN разъемы HARTING.
    [KPRM_02v2.DSN]
2014-02-07 Добавлена документация.
    [Плата КПРМ KPRM_02v2 (СБ).dwg]
2015-02-18 Изменены децимальные номера.
    [KPRM_02v2.DSN, Плата КПРМ KPRM_02v2 (СБ).dwg, Плата КПРМ ПБКМ.426439.005 02v2 (СБ).dwg]
2016-11-29 Добавлены гербера пасты.
    [KPRM_02v2.brd]
2018-07-23 Добавлены файлы заказа.
    [KPRM_02v2 20.12.13.xls, art_param.txt, nc_param.txt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]
2018-10-02 Добавлены СП и Э3 для нового артикула платы с 16 командами.
    [KPRM_02v2.DSN]
2018-10-02 Доделана документация для платы 1-16 2.141.180.
    [Плата КПРМ ПБКМ.426439.005 02v2 (СБ).dwg]
2018-10-03 На СБ у неполярных диодов убрана полоска (для этого добавлен дополнительный символ посадочного места).
    [diom5236x261n_np.psm]
